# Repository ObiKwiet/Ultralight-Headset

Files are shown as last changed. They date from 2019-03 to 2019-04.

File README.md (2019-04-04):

# Ultralight Headset
This is a project to make a better communications headset for ultralights, but specifically for paramotors. 

## Goals
- Modularity - Everyone's needs and budget are a little different, so we want to make it possible put together certain features a la carte.
- ANR - Active noise cancelation modules are rare for UL headsets, but they are the only way of effectively attenuating the low frequencies generated by our two stroke engines and prop. 
- Wireless links - The helmet itself should have a wireless link to other system components. Reducing the number of wires around us is not only convenient, but also an important safety improvement. This should also reduce cost and labor by eliminating a complex cable assembly, and expensive connectors.
- Radio connectivity - The system should accommodate at least two simultaneous analog radios, cell phone connectivity, and bluetooth intercom.  
- Side tone - The system should feed the microphone signal back into the speakers for the comfort of the user. 

## Roadmap
The roadmap lays out the requirements for each version of the headset along its development. 

### Version 1.0

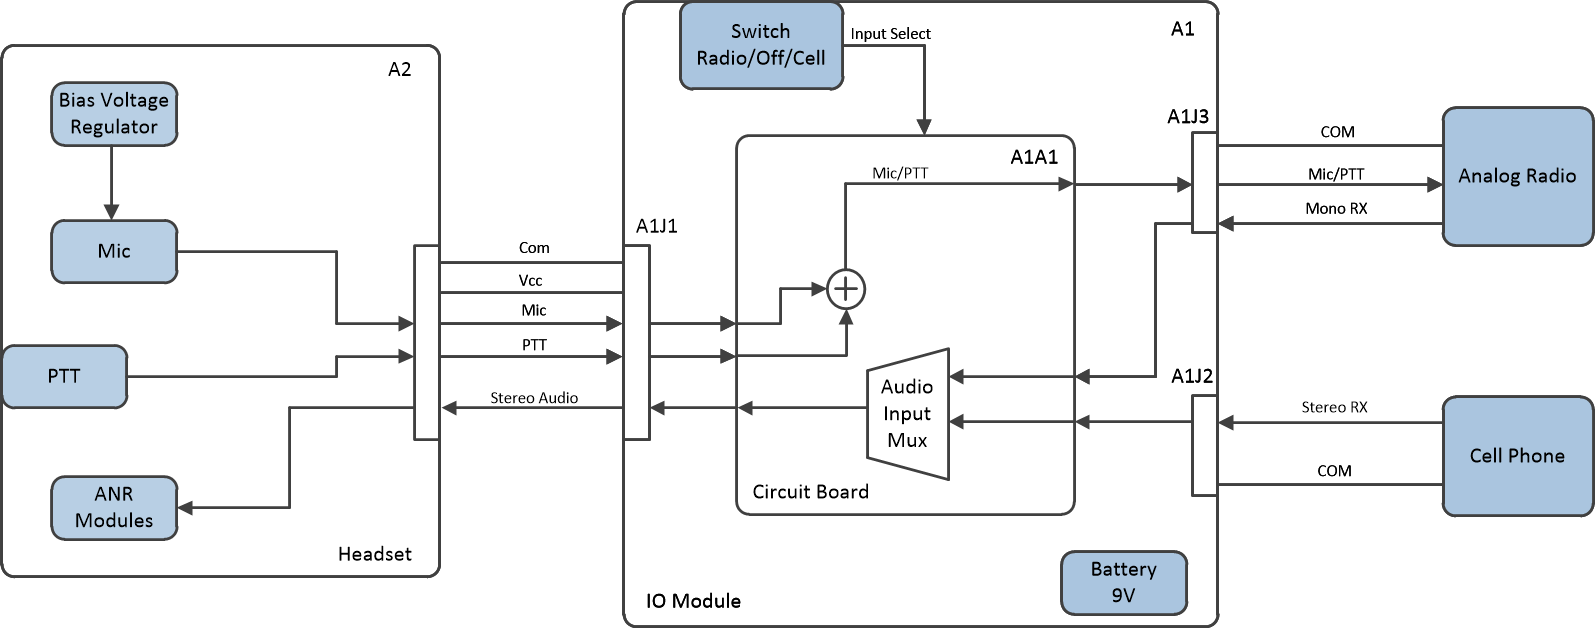
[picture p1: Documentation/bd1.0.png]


Version 1 and its derivatives have a fully wired interface between all modules. The first version supports a single radio, and audio input from an AUX jack. 

### Version 1.1

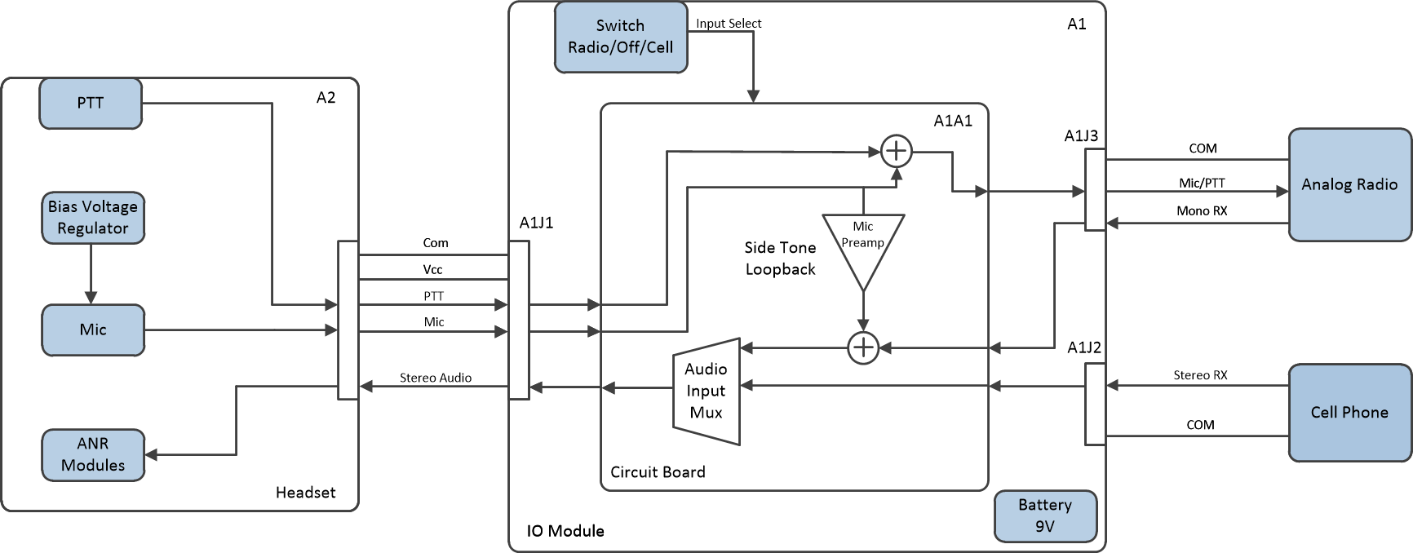
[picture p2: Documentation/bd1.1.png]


Version 1.1 will change the following items.

- Side tone support. Side tone plays audio from the microphone back through the speakers to allow the user to hear themselves speak. The greatly improves the comfort of speaking. 

- A generic pigtail drawing will be added so cable for arbitrary radios can easily be constructed. 

### Version 2.0

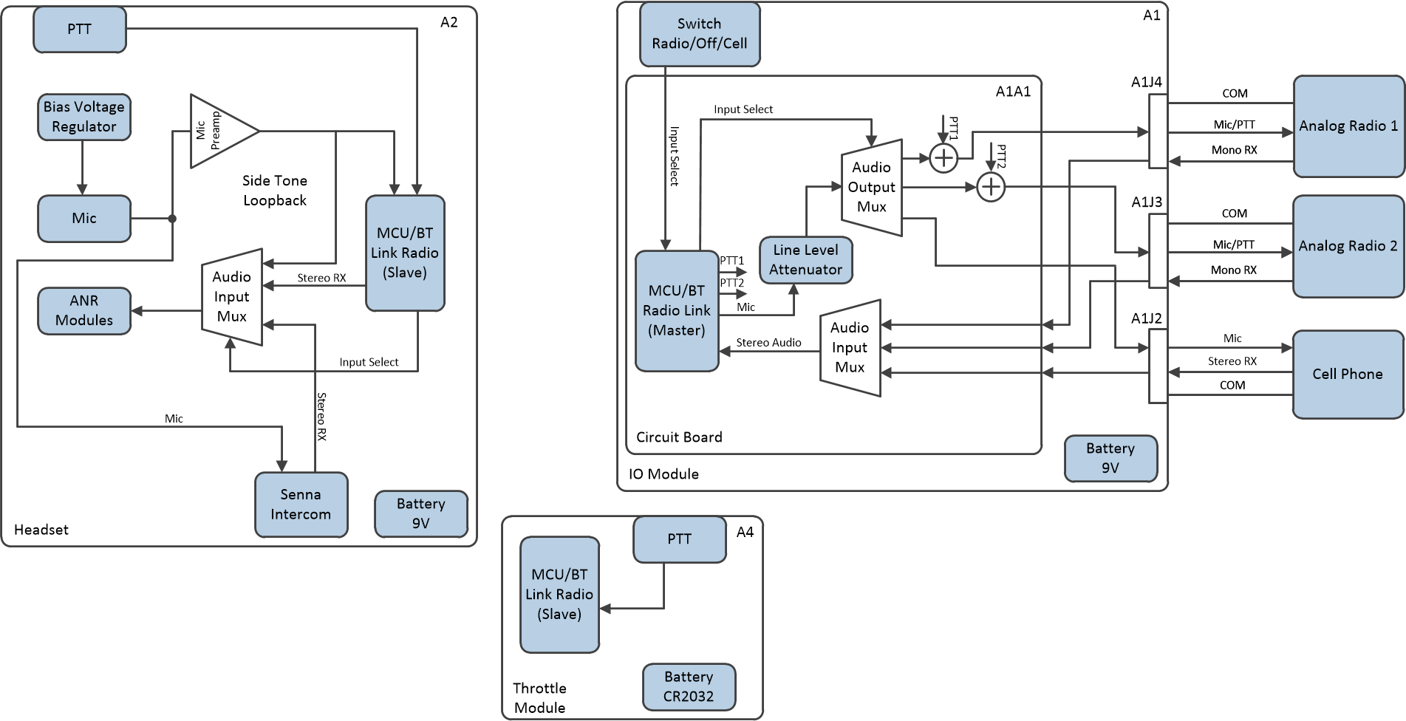
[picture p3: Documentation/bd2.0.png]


Version 2.0 will involve a major redesign, and significantly increase the design complexity of the headset. However, it should hopefully reduce overall cost and build difficulty. 

The following things will be completed for 2.0:

- The link between the IO Module and the Headset will be changed to a bluetooth interface. 

- The IO Module Case will be changed, and support for one additional analog radio will be added. 

- The connecters may be changed to reduce cost. 

- The radio toggle interface will need to be changed

- Support for Senna intercom may be added in a subversion.

- Throttle PTT will be added, but may be pushed to 2.1

- A battery will be added to the headset. 

- The microphone on the headset will change to a more robust aviation style

- Microphone input will be added to the aux jack

## Drawing Numbering and Style Guide

This is still WIP. For now I am trying to use a formal drawing tree. Drawings from various CAD softwares are printed to PDF and controlled in the Git repository, and source files will be kept in their own folder. Configuration management is TBD, but for the most part we will just add dash numbers to drawings of major changes to systems. 
Minor changes will be reflected by a change in the revision letter.  I will need to set up some configuration management spreadsheet to identify which dash numbers go into each version.  

## CAD Software 
Currently, Fusion360 is being used for mechanical CAD. Due to major shortcomings with the drafting module, it would be desirable to move to Solidworks. Solidworks is normally very expensive but is available through the EAA for use on open source projects. 
In the meantime, I'd be happy to add you to the Fusion360 project if you email me. There isn't any obvious way to link to it as a public repo.

Certain drawings are maintained on sheets, which has the advantage of being free, and the major disadvantage of not having version control synced with the repository. 
- [Wirelists for A1300](https://docs.google.com/spreadsheets/d/1odUo59O54lUUatiMipqJTk2xvd_l8rzADcac63PmRdw/edit?usp=sharing)
- [Partlists](https://docs.google.com/spreadsheets/d/1oErzroamnteU2tq9hoaM70eOOeuBpsWLLE8QT7xZNOo/edit?usp=sharing)
- [Drawing Tree](https://docs.google.com/spreadsheets/d/1H3n_jioX6qo1rZ_G6kWBhMTz45Bp03Awh5uix86TeiI/edit?usp=sharing)

KiCad will be used for electrical schematics and PCBs. 

Currently, we don't really have proper wiring diagrams, but these will probably be done with AutoCad electrical, due to a total lack of free software to do the job. There aren't any reasonably priced ways to get AutoCad unless you are a student, so finding a work around will be up to you. 

## Assembly Guide

I was going to write up a detailed assembly guide, but at this point the project isn't really in a solid enough state to be used by someone who can't figure it out well enough from the drawings. This will have to wait for 2.0. 

## Pictures

These are some images of the 1.0 version. 
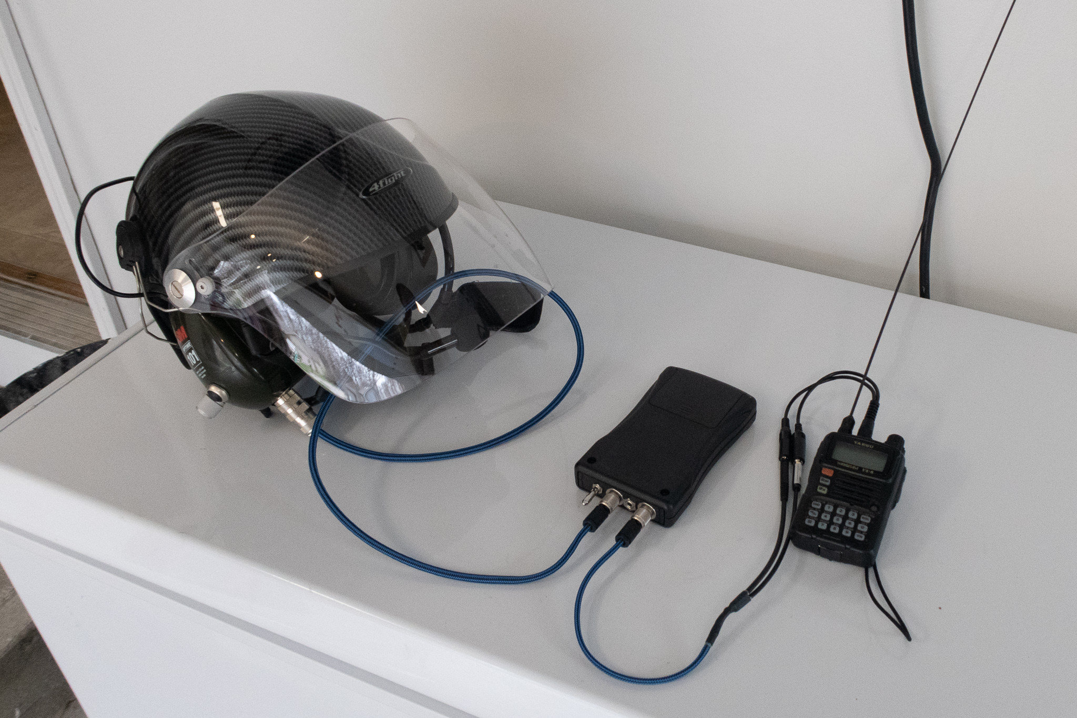
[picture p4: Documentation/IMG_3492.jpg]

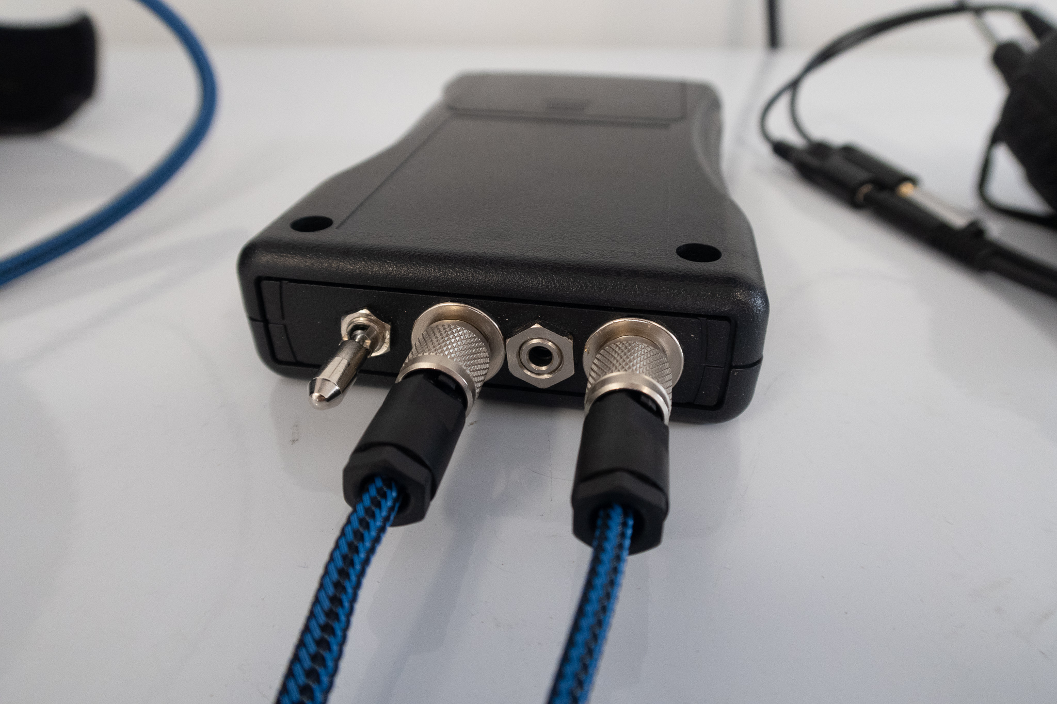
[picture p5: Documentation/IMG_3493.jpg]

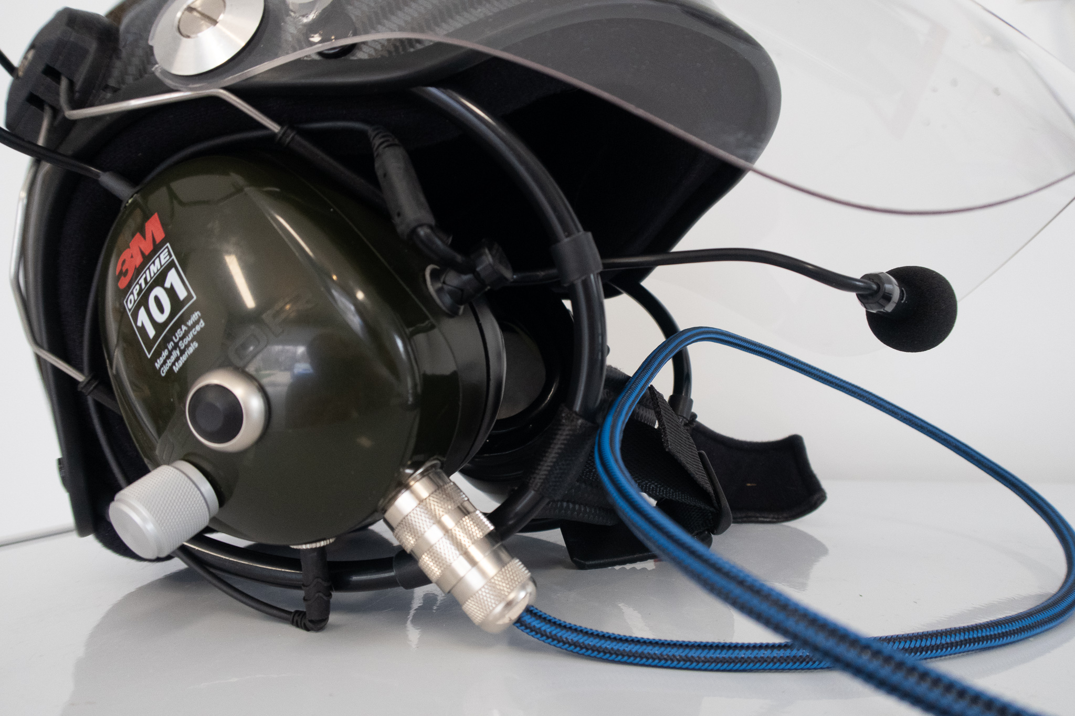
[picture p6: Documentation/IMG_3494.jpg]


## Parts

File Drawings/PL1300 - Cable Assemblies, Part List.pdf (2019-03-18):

Drawing | PL1300 | Description | Cable Assemblies
Rev | A
Quantity per assembly dash number
Find No. Part Number | -1 | -2 | -3 | Manufactuer | Description | Notes
1 | 2.5mm Connector | 1 | Plug | Source from double ended 3.5mm to 2.5mm adapter
2 | 3.5mm Connector | 1 | Plug | Source from double ended 3.5mm to 2.5mm adapter
3 | 99 0425 00 05 | 1 | 1 | Binder | Plug
4 | K2 Connector | 1 | BTECH | Plug | See Note 3
5 | 99 5171 40 08 | 1 | Binder | Plug
6 | 99 0425 00 08 | 1 | Binder | Plug
7 | Carbon BTI MDPC-X Small Sleeve | 4ft | 2ft | 2ft | MDPC-X | Sleeving
8 | Wire | 4ft | 2ft | 2ft | 26AWG, stranded, shielded. Source from Cat 6, or 7
9 | HS3A-025 | 1ft | 1ft | Heat Shrink

Notes - * Indicates Flag Note
1* | Cut Find no. 7 to length and install over wiring
2* | Cut find no. 9 to length and install over splice. Solder spliced connections and

cover each with standard heatshrink
3 Cut 2 pin connector off of "3.5MM Adaptor", leave 100mm of cable

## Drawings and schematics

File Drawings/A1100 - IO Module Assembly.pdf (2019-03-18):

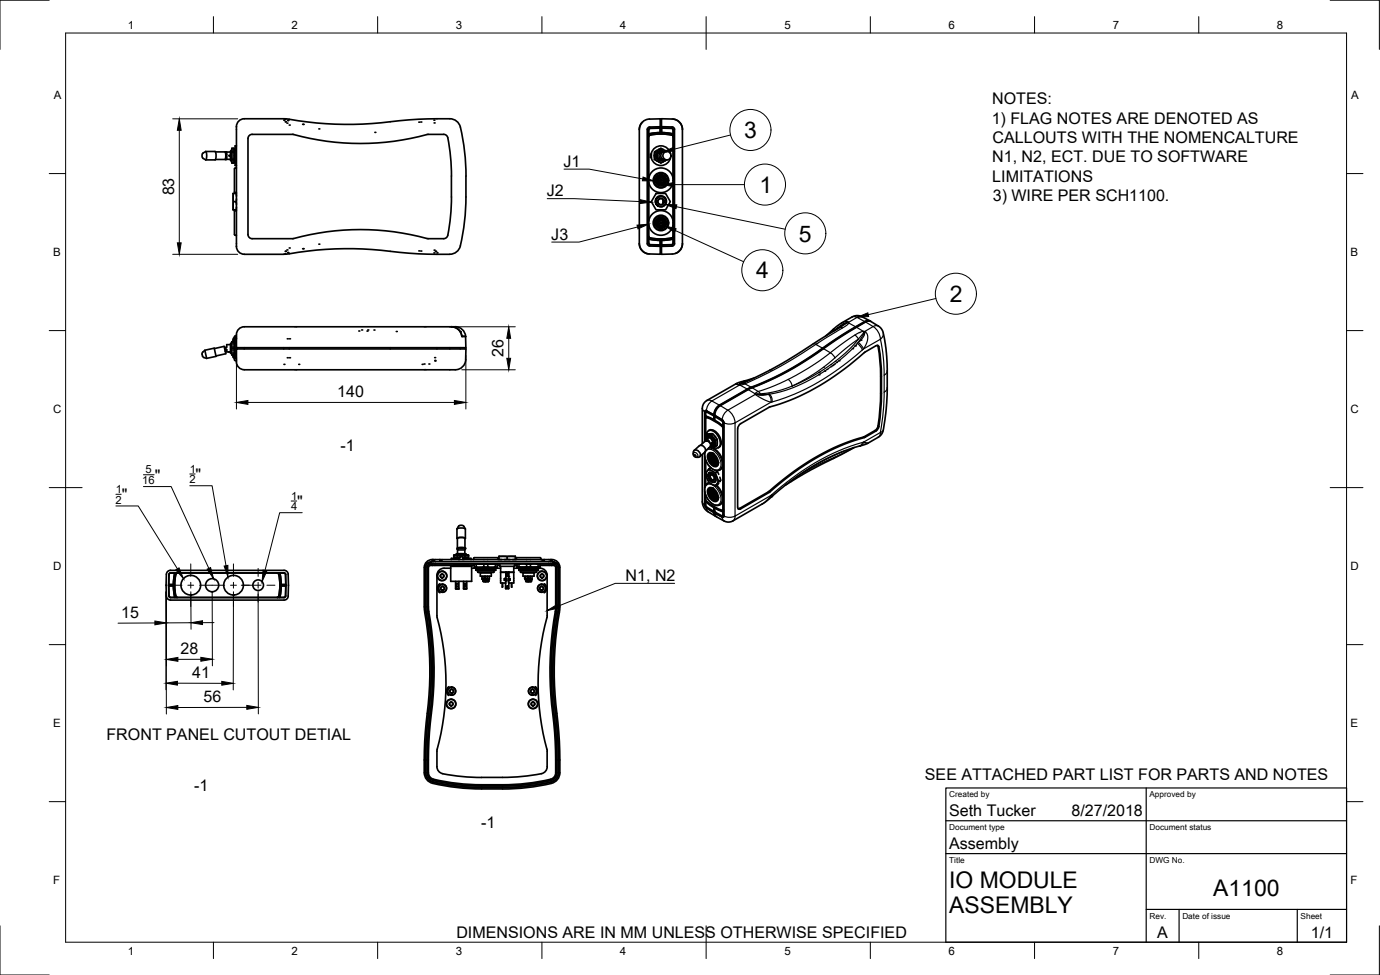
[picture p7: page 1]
Created by; Approved by; Seth Tucker

NOTES:
1) FLAG NOTES ARE DENOTED AS
CALLOUTS WITH THE NOMENCALTURE
N1, N2, ECT. DUE TO SOFTWARE
LIMITATIONS
3) WIRE PER SCH1100.

FRONT PANEL CUTOUT DETIAL

SEE ATTACHED PART LIST FOR PARTS AND NOTES -1

Document type Assembly | Document status

Title ASSEMBLY | DWG No. A1100 IO MODULE

Rev. A | Date of issue | Sheet 1/1

DIMENSIONS ARE IN MM UNLESS OTHERWISE SPECIFIED

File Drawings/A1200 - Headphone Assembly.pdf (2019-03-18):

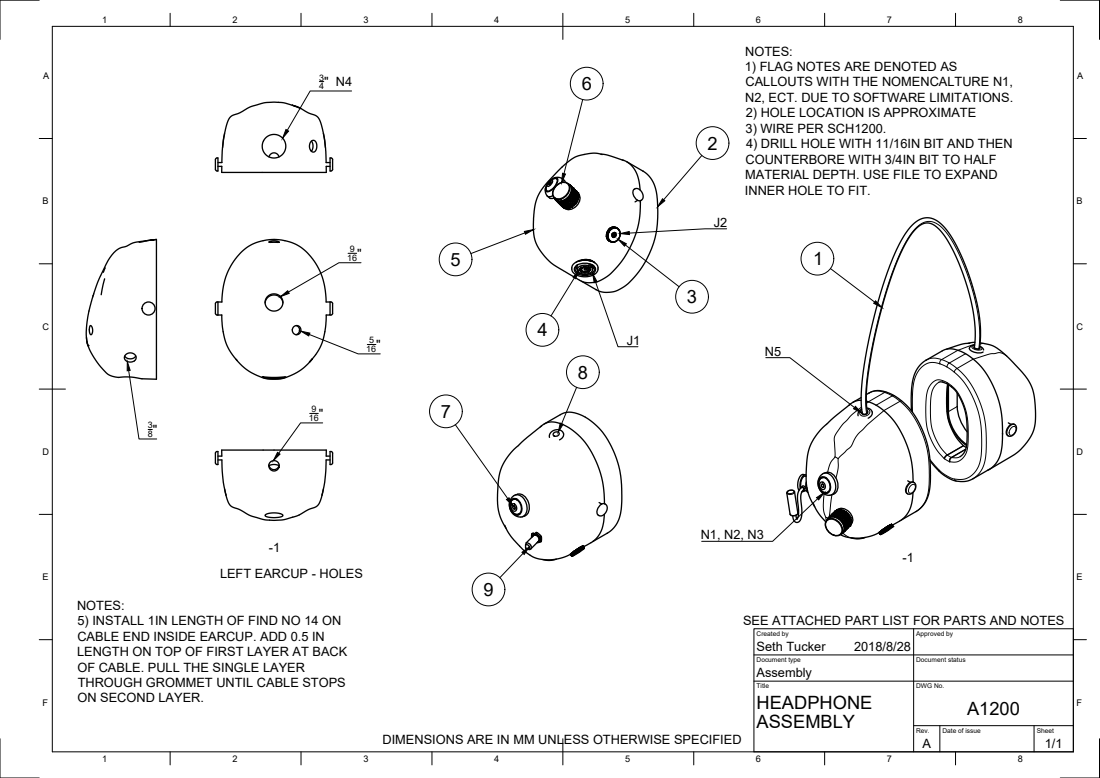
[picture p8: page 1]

NOTES:
1) FLAG NOTES ARE DENOTED AS
CALLOUTS WITH THE NOMENCALTURE N1,
N2, ECT. DUE TO SOFTWARE LIMITATIONS.
2) HOLE LOCATION IS APPROXIMATE
3) WIRE PER SCH1200.

4) DRILL HOLE WITH 11/16IN BIT AND THEN
COUNTERBORE WITH 3/4IN BIT TO HALF
MATERIAL DEPTH. USE FILE TO EXPAND
INNER HOLE TO FIT.

LEFT EARCUP - HOLES

5) INSTALL 1IN LENGTH OF FIND NO 14 ON
CABLE END INSIDE EARCUP. ADD 0.5 IN
LENGTH ON TOP OF FIRST LAYER AT BACK
OF CABLE. PULL THE SINGLE LAYER
THROUGH GROMMET UNTIL CABLE STOPS
ON SECOND LAYER.

SEE ATTACHED PART LIST FOR PARTS AND NOTES

Created by Seth Tucker 2018/8/28 | Approved by

Document type Assembly | Document status

Title HEADPHONE ASSEMBLY | DWG No. A1200

DIMENSIONS ARE IN MM UNLESS OTHERWISE SPECIFIED

Rev. A | Date of issue | Sheet 1/1

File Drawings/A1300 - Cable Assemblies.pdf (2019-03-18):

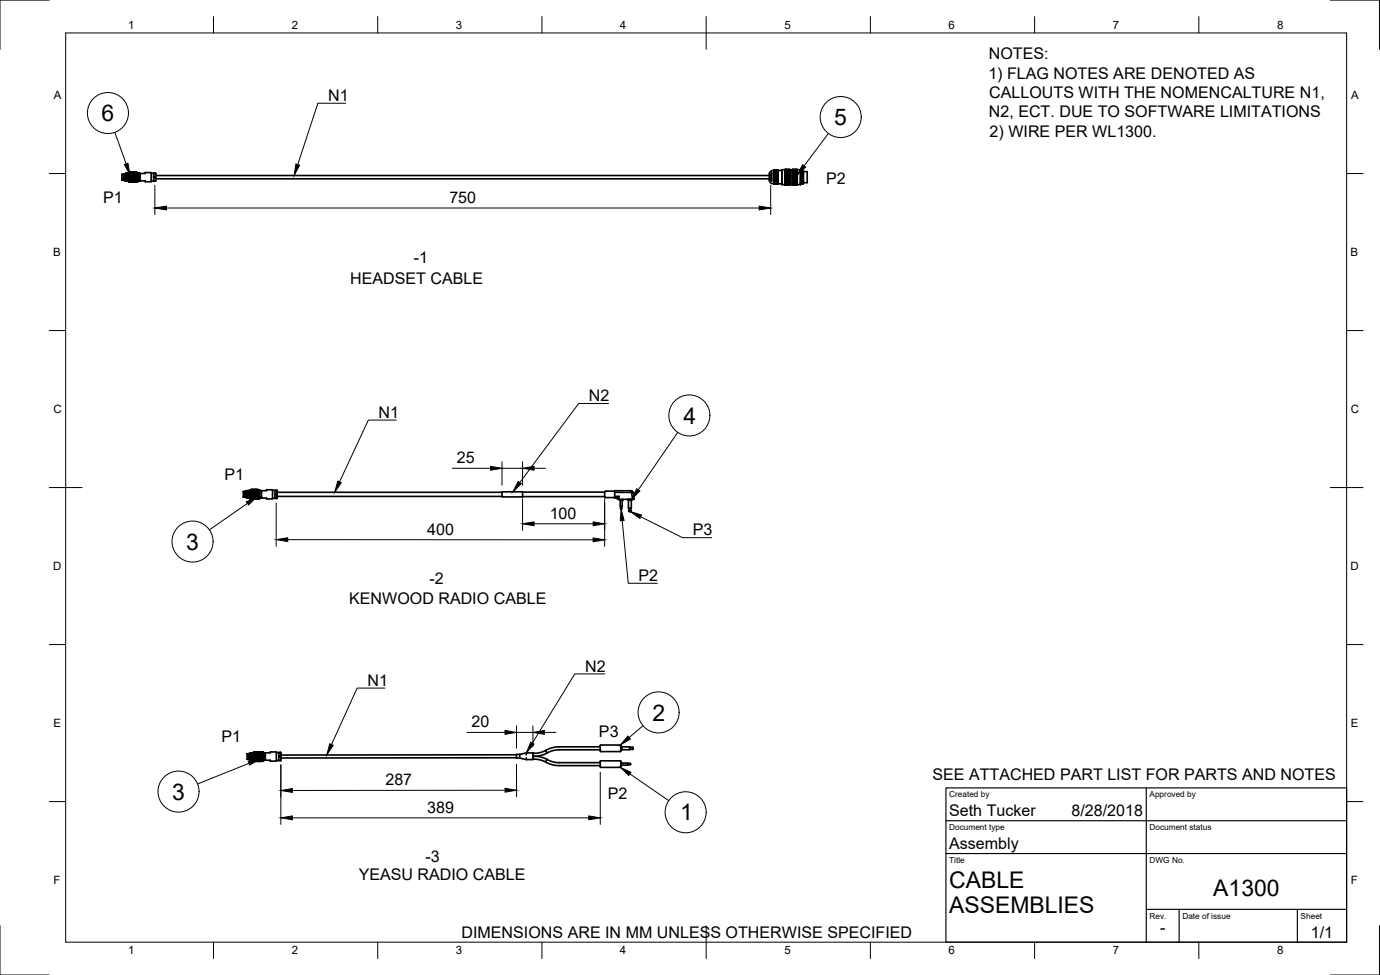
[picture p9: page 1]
Created by; Approved by; Document type; Document status; Title; DWG No.; Rev.; Date of issue; Sheet - Assembly; Seth Tucker; HEADSET CABLE

NOTES:
1) FLAG NOTES ARE DENOTED AS
CALLOUTS WITH THE NOMENCALTURE N1,
N2, ECT. DUE TO SOFTWARE LIMITATIONS
2) WIRE PER WL1300.

KENWOOD RADIO CABLE

SEE ATTACHED PART LIST FOR PARTS AND NOTES

YEASU RADIO CABLE

DIMENSIONS ARE IN MM UNLESS OTHERWISE SPECIFIED

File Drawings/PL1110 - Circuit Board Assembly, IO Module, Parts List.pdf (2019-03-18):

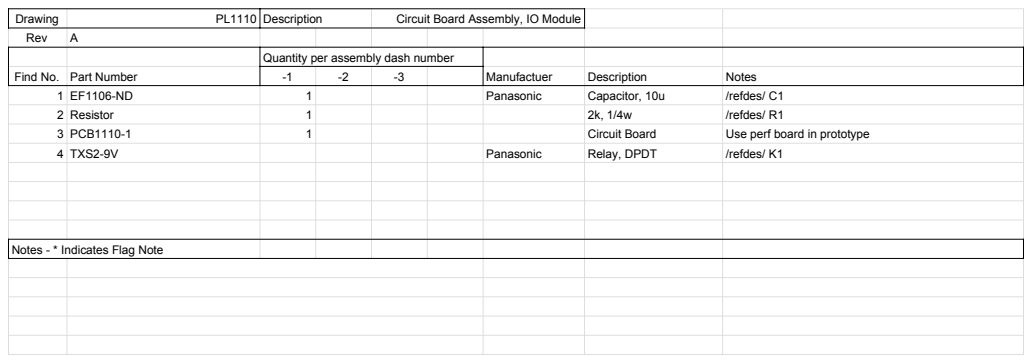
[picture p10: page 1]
Drawing; Description; Circuit Board Assembly, IO Module; Rev; Find No. Part Number; Manufactuer; Notes; Panasonic; Capacitor, 10u; /refdes/ C1; 2 Resistor; /refdes/ R1; 3 PCB1110-1; Circuit Board; Use perf board in prototype; 4 TXS2-9V; Relay, DPDT; /refdes/ K1

Quantity per assembly dash number

Notes - * Indicates Flag Note

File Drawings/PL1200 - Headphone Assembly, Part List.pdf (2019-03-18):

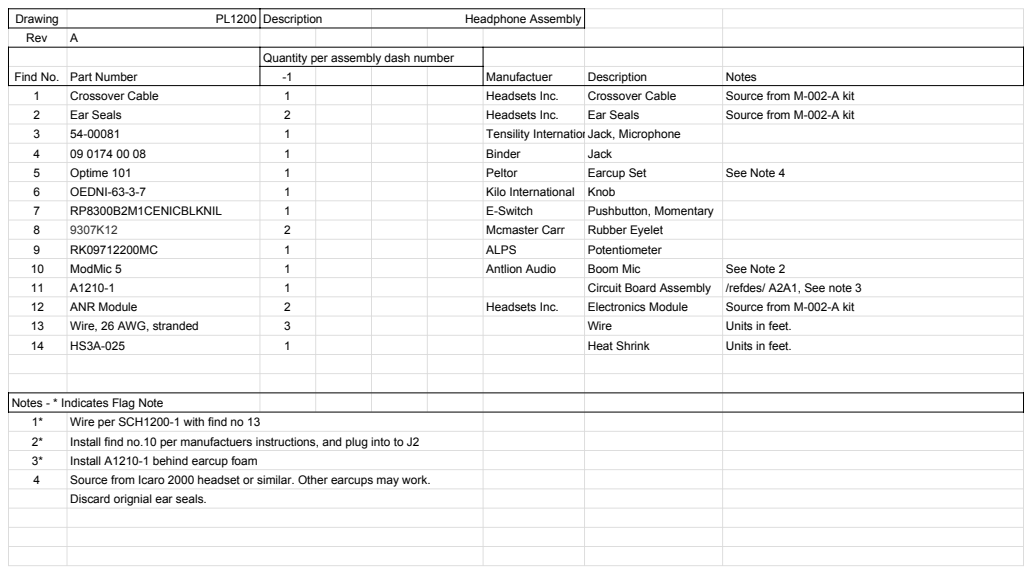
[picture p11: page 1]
Drawing; Description; Headphone Assembly; Rev; Find No. Part Number; Manufactuer; Notes; Crossover Cable; Headsets Inc.; Source from M-002-A kit; Ear Seals; Tensility International Corp Jack, Microphone; Binder; Jack; Optime 101; Peltor; Earcup Set; See Note 4; OEDNI-63-3-7; Kilo International Knob; RP8300B2M1CENICBLKNIL; E-Switch; Pushbutton, Momentary; Mcmaster Carr; Rubber Eyelet; ALPS; Potentiometer; ModMic 5; Antlion Audio; Boom Mic; See Note 2; Circuit Board Assembly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

Quantity per assembly dash number

Notes - * Indicates Flag Note

Discard orignial ear seals.

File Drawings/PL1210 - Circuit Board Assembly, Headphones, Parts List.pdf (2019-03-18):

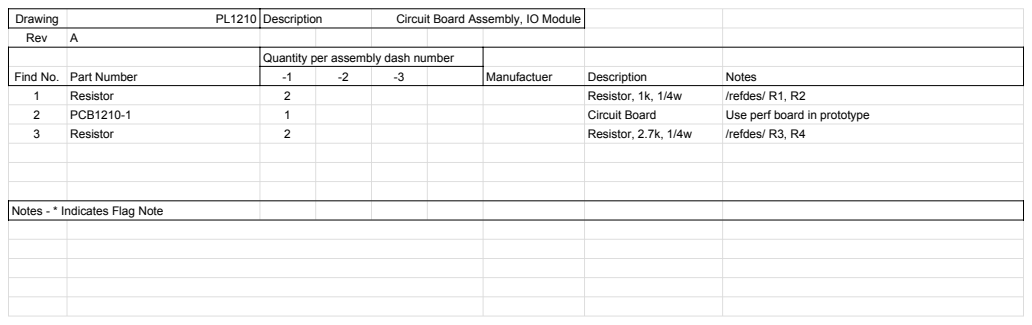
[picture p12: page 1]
Drawing; Description; Circuit Board Assembly, IO Module; Rev; Find No. Part Number; Manufactuer; Notes; Resistor; Resistor, 1k, 1/4w; /refdes/ R1, R2; PCB1210-1; Circuit Board; Use perf board in prototype; Resistor, 2.7k, 1/4w; /refdes/ R3, R4

Quantity per assembly dash number

Notes - * Indicates Flag Note

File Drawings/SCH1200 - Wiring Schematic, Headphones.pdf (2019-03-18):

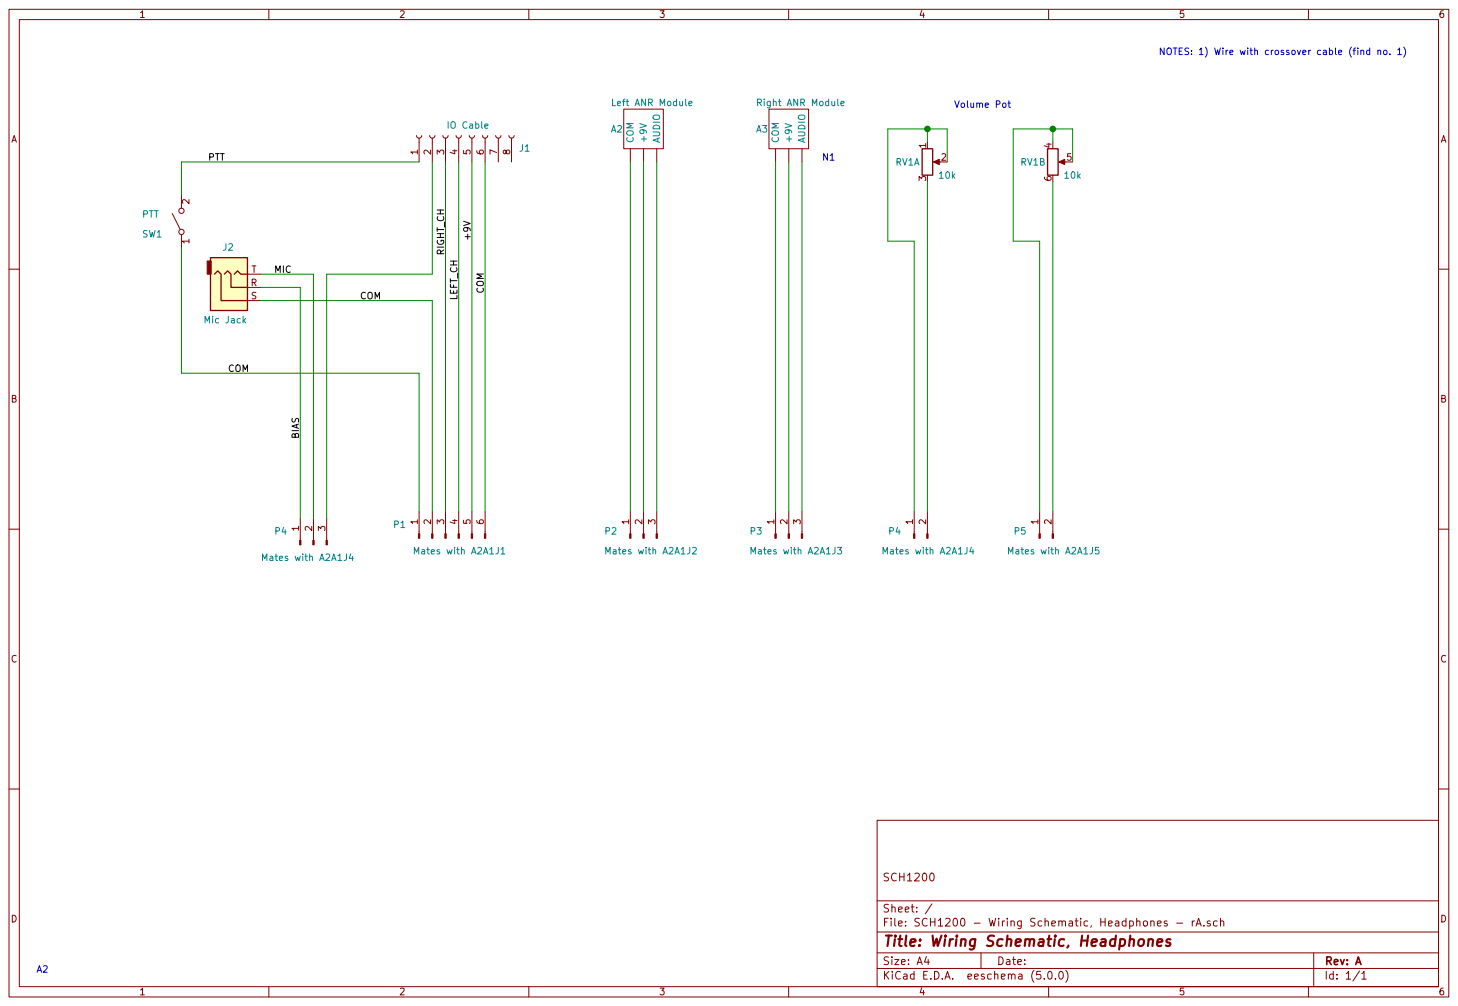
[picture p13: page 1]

File: SCH1200 - Wiring Schematic, Headphones - rA.sch Sheet: / SCH1200

Id: 1/1 Title: Wiring Schematic, Headphones

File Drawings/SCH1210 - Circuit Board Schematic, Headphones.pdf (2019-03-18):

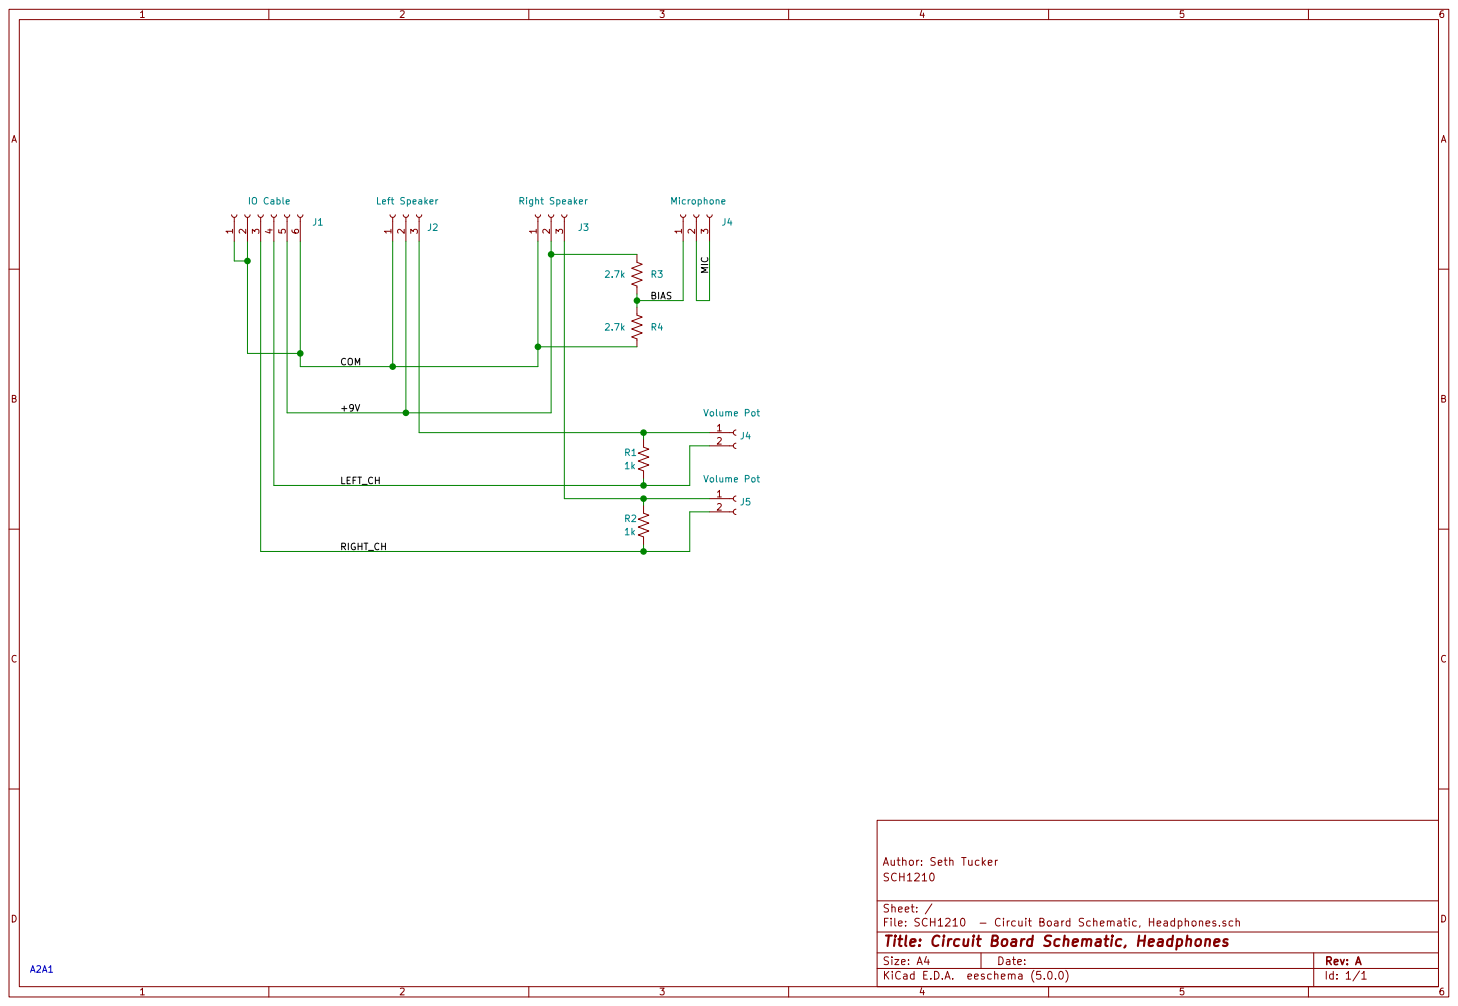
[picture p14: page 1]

File: SCH1210 - Circuit Board Schematic, Headphones.sch Sheet: / SCH1210 Author: Seth Tucker

Id: 1/1 Title: Circuit Board Schematic, Headphones

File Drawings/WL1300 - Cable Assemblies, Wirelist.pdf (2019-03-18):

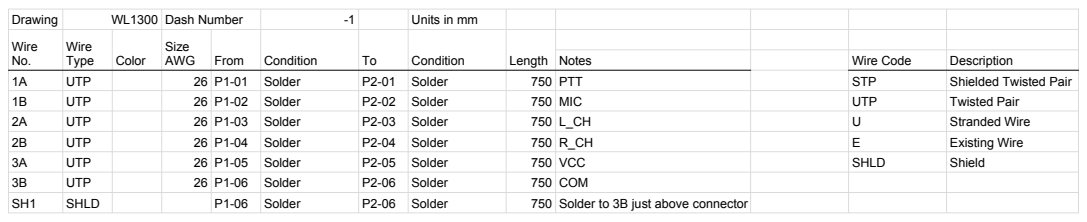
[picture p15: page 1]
Drawing; WL1300 Dash Number; Units in mm; Wire No.; Wire; Type; Color; Size; AWG; From; Condition; Length Notes; Wire Code; Description; UTP; Solder; 750 PTT; STP; Shielded Twisted Pair; 750 MIC; Twisted Pair; Stranded Wire; Existing Wire; 750 VCC; SHLD; Shield; 750 COM; 750 Solder to 3B just above connector

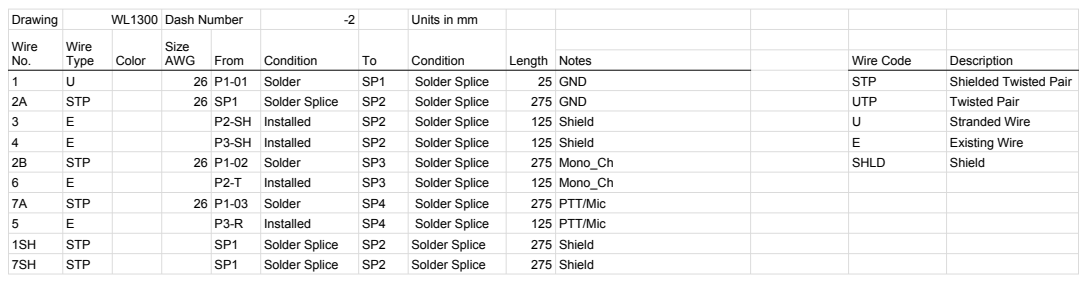
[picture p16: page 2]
Drawing; WL1300 Dash Number; Units in mm; Wire No.; Wire; Type; Color; Size; AWG; From; Condition; Length Notes; Wire Code; Description; Solder; Solder Splice; 25 GND; STP; Shielded Twisted Pair; 275 GND; UTP; Twisted Pair; P2-SH Installed; 125 Shield; Stranded Wire; P3-SH Installed; Existing Wire; 275 Mono_Ch; SHLD; Shield; Installed; 125 Mono_Ch; 275 PTT/Mic; 125 PTT/Mic; 275 Shield

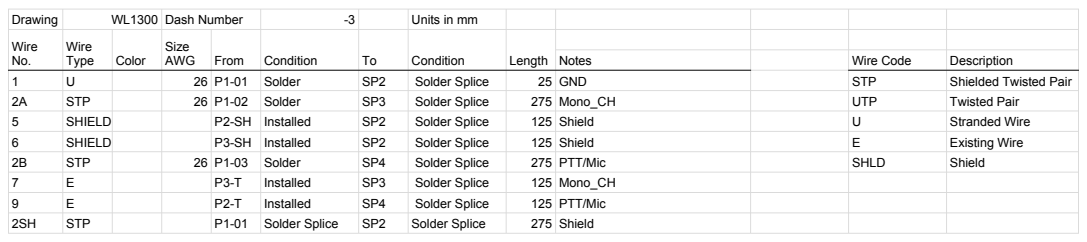
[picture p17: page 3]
Drawing; WL1300 Dash Number; Units in mm; Wire No.; Wire; Type; Color; Size; AWG; From; Condition; Length Notes; Wire Code; Description; Solder; Solder Splice; 25 GND; STP; Shielded Twisted Pair; 275 Mono_CH; UTP; Twisted Pair; SHIELD; P2-SH Installed; 125 Shield; Stranded Wire; P3-SH Installed; Existing Wire; 275 PTT/Mic; SHLD; Shield; Installed; 125 Mono_CH; 125 PTT/Mic; 275 Shield

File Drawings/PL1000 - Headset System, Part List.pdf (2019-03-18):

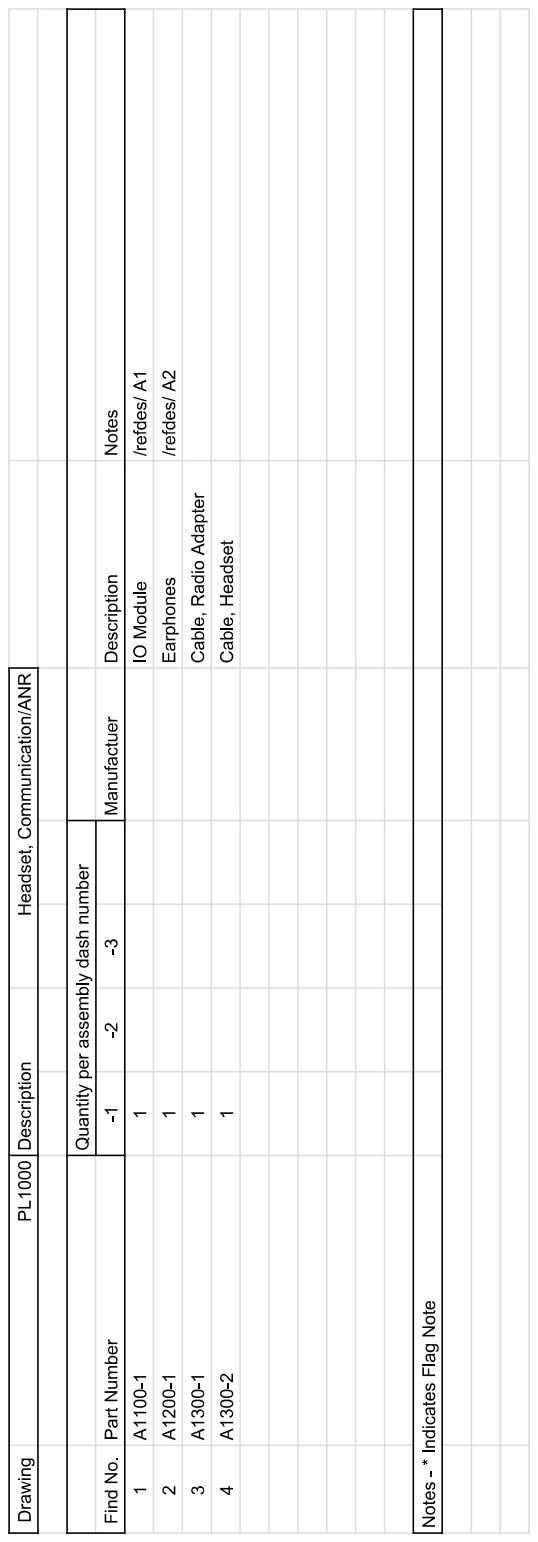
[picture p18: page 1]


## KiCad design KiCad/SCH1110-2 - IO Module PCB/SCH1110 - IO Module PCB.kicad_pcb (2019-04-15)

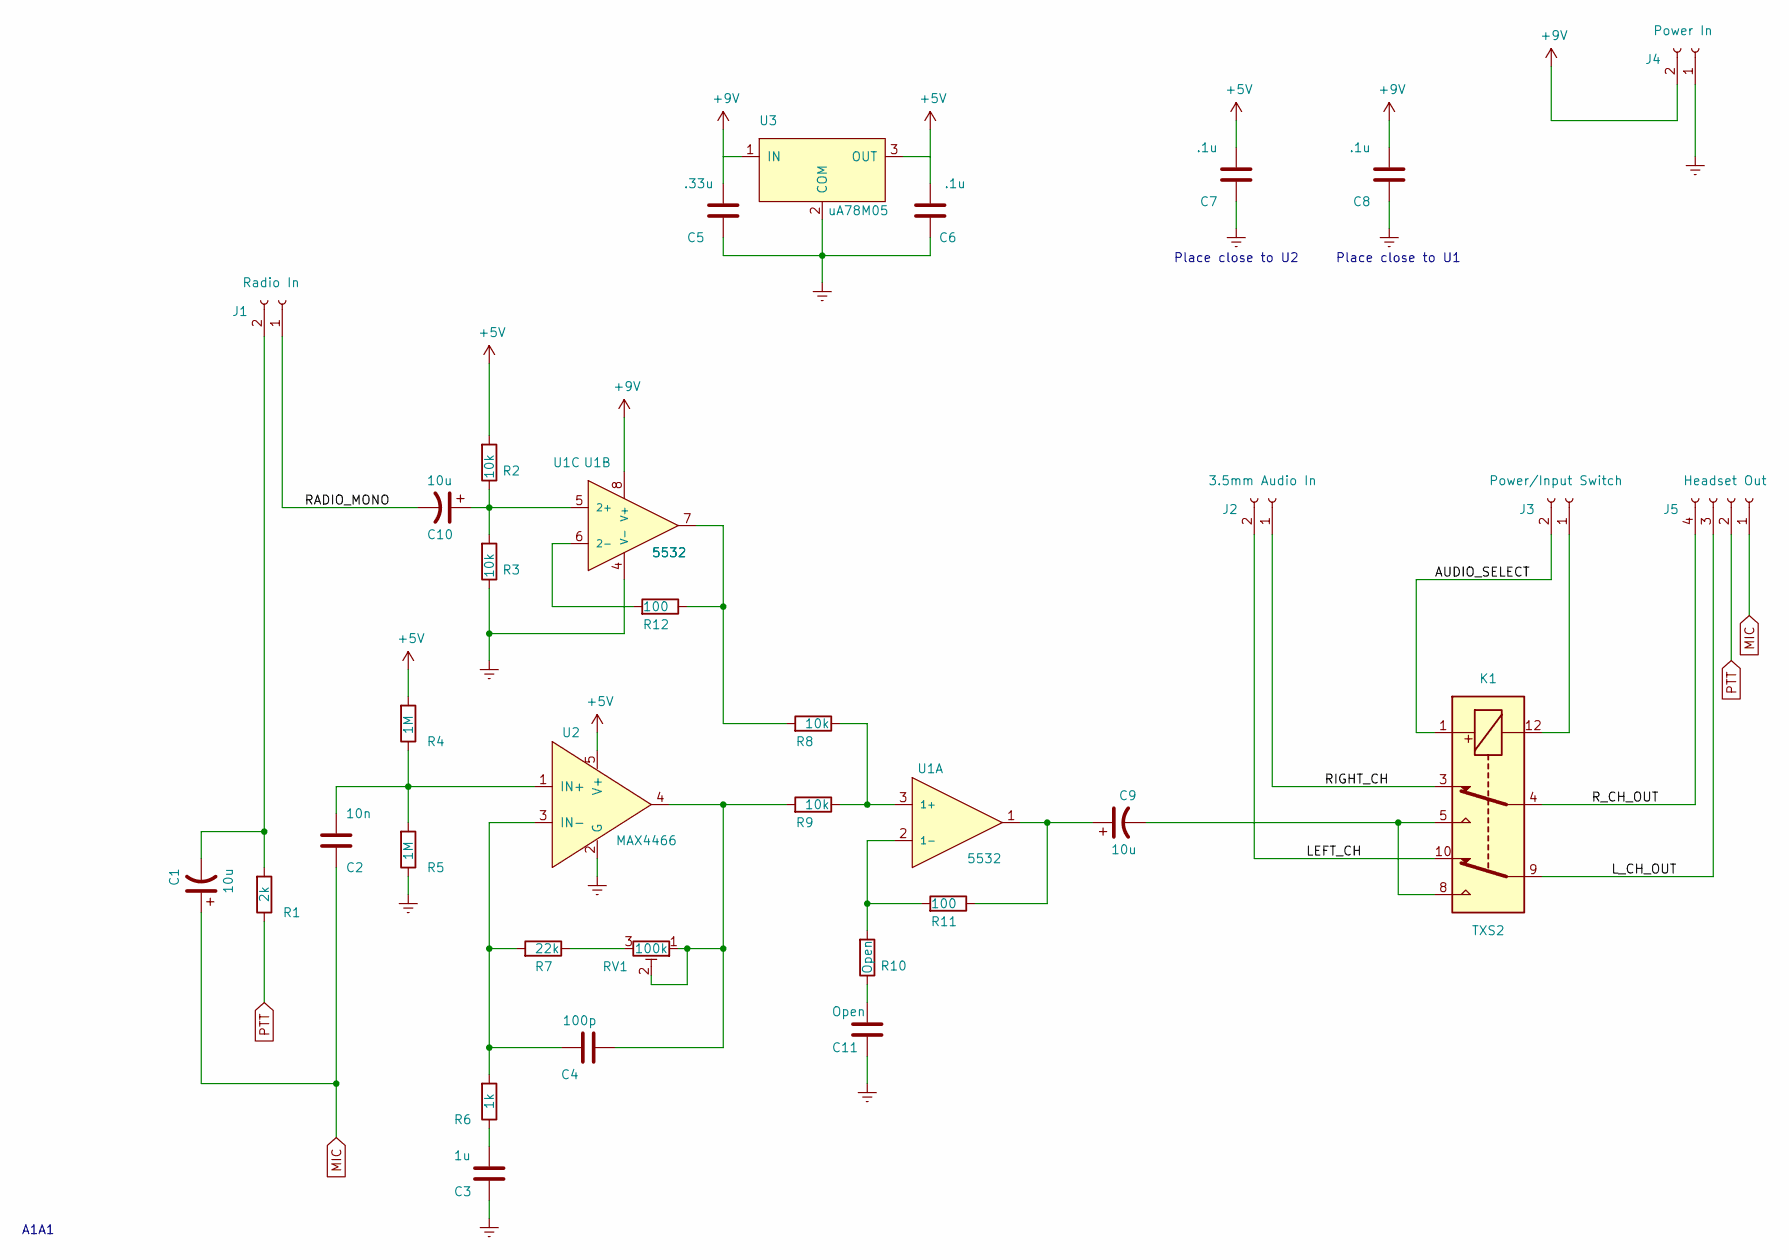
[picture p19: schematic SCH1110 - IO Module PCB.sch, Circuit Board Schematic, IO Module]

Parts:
C1, C9, C10: 10u; CP_Radial_D6.3mm_P2.50mm
C2: 10n; 0603
C3: 1u; 0805
C4: 100p; 0603
C5: .33u; 0805
C6, C7, C8: .1u; 0603
C11: Open; 0805
J1: Radio In; WP-75mil-1x02
J2: 3.5mm Audio In; WP-75mil-1x02
J3: Power/Input Switch; WP-75mil-1x02
J4: Power In; WP-75mil-1x02
J5: Headset Out; WP-75mil-1x04
K1: TXS2; TXS2-THT
R1: 2k; 0603
R2, R3, R8, R9: 10k; 0603
R4, R5: 1M; 0603
R6: 1k; 0603
R7: 22k; 0603
R10: Open; 0603
R11, R12: 100; 0603
RV1: 100k; Potentiometer_Bourns_3224X_Vertical
U1: 5532; SOIC-8_W3.9mm
U2: MAX4466; SOT-353
U3: uA78M05; Trans_SOT-223-4

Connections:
+5V: C6.2, C7.2, R2.2, R4.2, U2.5 (V+), U3.3 (OUT)
+9V: C5.2, C8.2, J4.2, U1.8 (V+), U3.1 (IN)
/AUDIO_SELECT: J3.2, K1.1
/LEFT_CH: J2.2, K1.10
/L_CH_OUT: J5.3, K1.9
/RADIO_MONO: C10.2, J1.1
/RIGHT_CH: J2.1, K1.3
/R_CH_OUT: J5.4, K1.4
Earth: C3.2, C5.1, C6.1, C7.1, C8.1, C11.2, J4.1, R3.1, R5.1, U1.4 (V-), U2.2 (G), U3.2 (COM)
MIC: C1.1, C2.2, J5.1
unnamed: C1.2, J1.2, R1.2
unnamed: C2.1, R4.1, R5.2, U2.1 (IN+)
unnamed: C3.1, R6.1
unnamed: C4.1, R6.2, R7.2, U2.3 (IN-)
unnamed: C4.2, R9.2, RV1.1, RV1.2, U2.4
unnamed: C9.1, R11.1, U1.1
unnamed: C9.2, K1.5, K1.8
unnamed: C10.1, R2.1, R3.2, U1.5 (2+)
unnamed: C11.1, R10.1
unnamed: J3.1, K1.12
unnamed: R7.1, RV1.3
unnamed: R8.1, R9.1, U1.3 (1+)
unnamed: R10.2, R11.2, U1.2 (1-)
unnamed: R8.2, R12.1, U1.7
unnamed: R12.2, U1.6 (2-)
PTT: J5.2, R1.1

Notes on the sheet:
A1A1
Place close to U2
Place close to U1

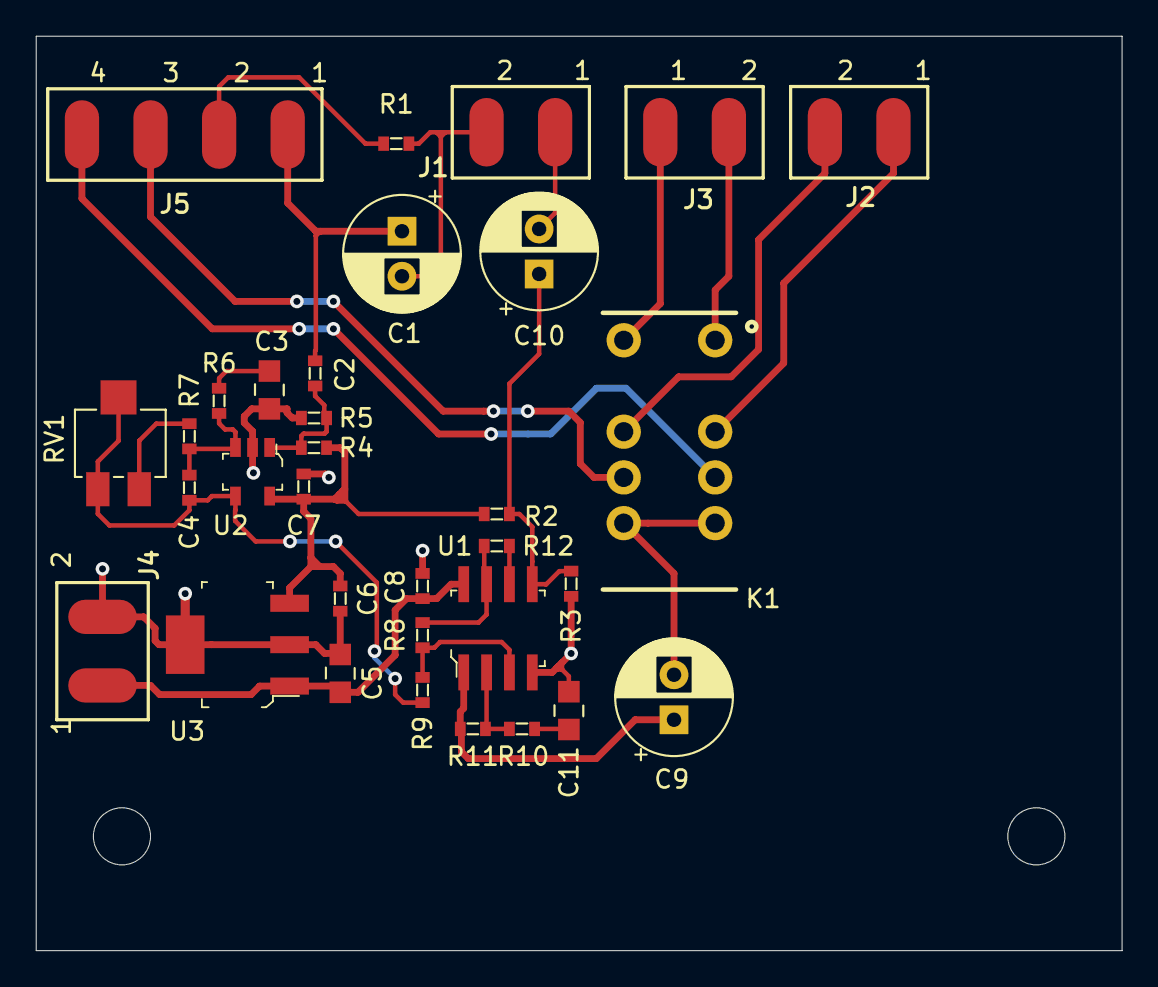
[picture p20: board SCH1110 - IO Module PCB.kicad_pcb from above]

Board: 2 copper layers, 60.3 x 50.8 mm, 33 parts (0 on the bottom side), 26 nets.

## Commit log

2019-03-18 Initial Commit of Files
    Rev A as built of first prototype.
    [SCH1100 - IO Module.kicad_pcb, SCH1100 - IO Module.sch, SCH1110 - IO Module PCB.kicad_pcb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]
2019-04-12 Added SCH1110-2
    [SCH1100 - IO Module.kicad_pcb, SCH1100 - IO Module.sch, SCH1110 - IO Module PCB.kicad_pcb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]
2019-04-15 Review changes and adjustments
    [SCH1110 - IO Module PCB-B_Cu.gbl, SCH1110 - IO Module PCB-B_Mask.gbs, SCH1110 - IO Module PCB-B_Paste.gbp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]
2019-04-15 Final for this rev. Added gerbers and drills.
    [SCH1110 - IO Module PCB.kicad_pcb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]
2019-06-02 Incorporated redlines for -2 PCB and wiring schematics.
    [SCH1100 - IO Module.sch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]
